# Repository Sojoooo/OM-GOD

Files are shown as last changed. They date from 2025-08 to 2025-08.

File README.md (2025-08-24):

<h1 align="center">
  <br>
  OM-GOD
  <br>
</h1>

<h4 align="center">
Ominichord [Gate of Divinity]. Mash-up of all the previous omnichords and more.
</h4>

<div align="center">





</div>

<p align="center">
  <a href="#key-features">Key Features</a> •
  <a href="#design-process">Design Process</a> •
  <a href="#pcb">PCB</a> •
  <a href="#bom">BOM</a> •
  <a href="#journal">Development Journal</a> •
  <a href="#credits">Credits</a> •
  <a href="#license">License</a>
</p>

## Key Features

- **STM32H7 microcontroller** for high-performance processing
- **Texas Instruments DACs and amplifiers** for professional audio quality
- **MIDI connectivity** for external device integration
- **USB-C programming and power delivery**
- **Battery-powered portable design**
- **Cherry MX mechanical switches** for tactile feedback
- **48-button chord matrix** (4 rows × 12 buttons)
- **Rotary encoders** for parameter control
- **LED display** for status and settings

## Design Process

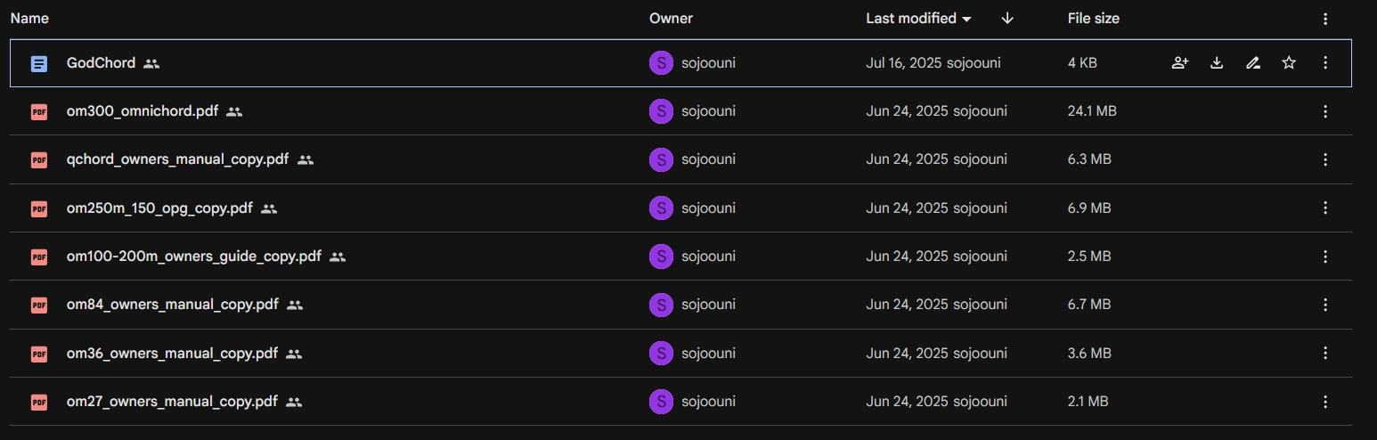
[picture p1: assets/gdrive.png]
Google Drive Reference


The OM-GOD project began with extensive research into existing omnichord designs and their features. After compiling schematics and manuals, I created a comprehensive feature list to guide the development process.

## PCB

Designed in KiCad with a focus on audio quality and modern features. Notable components:

- **STM32H7** microcontroller with 144 GPIO pins
- **PCM5122PW DAC** for high-quality audio conversion
- **TPA3116D2DAD Class D amplifier** for powerful audio output
- **BQ24610** battery charging circuit for portable operation
- **Multiple voltage regulators** (12V, 15V, 5V, 3.3V)
- **USB-C power delivery** with negotiator circuit
- **NFC antenna** for contactless communication

### Schematic Development

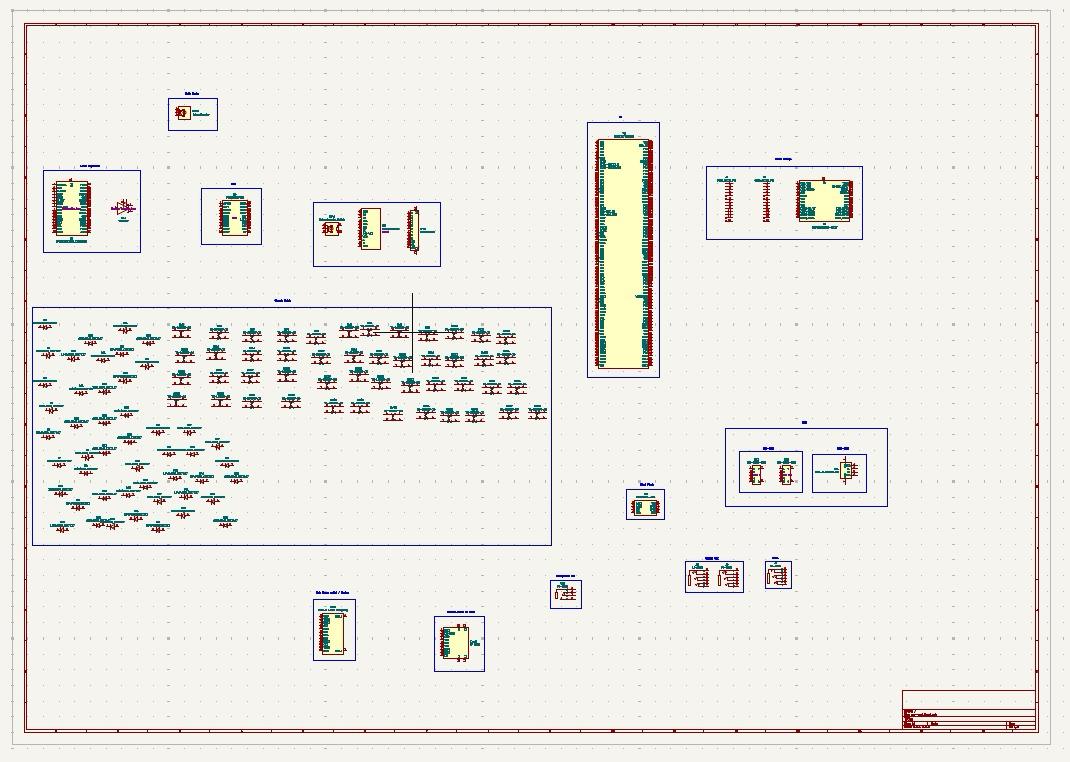
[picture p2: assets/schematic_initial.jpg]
Initial Schematic

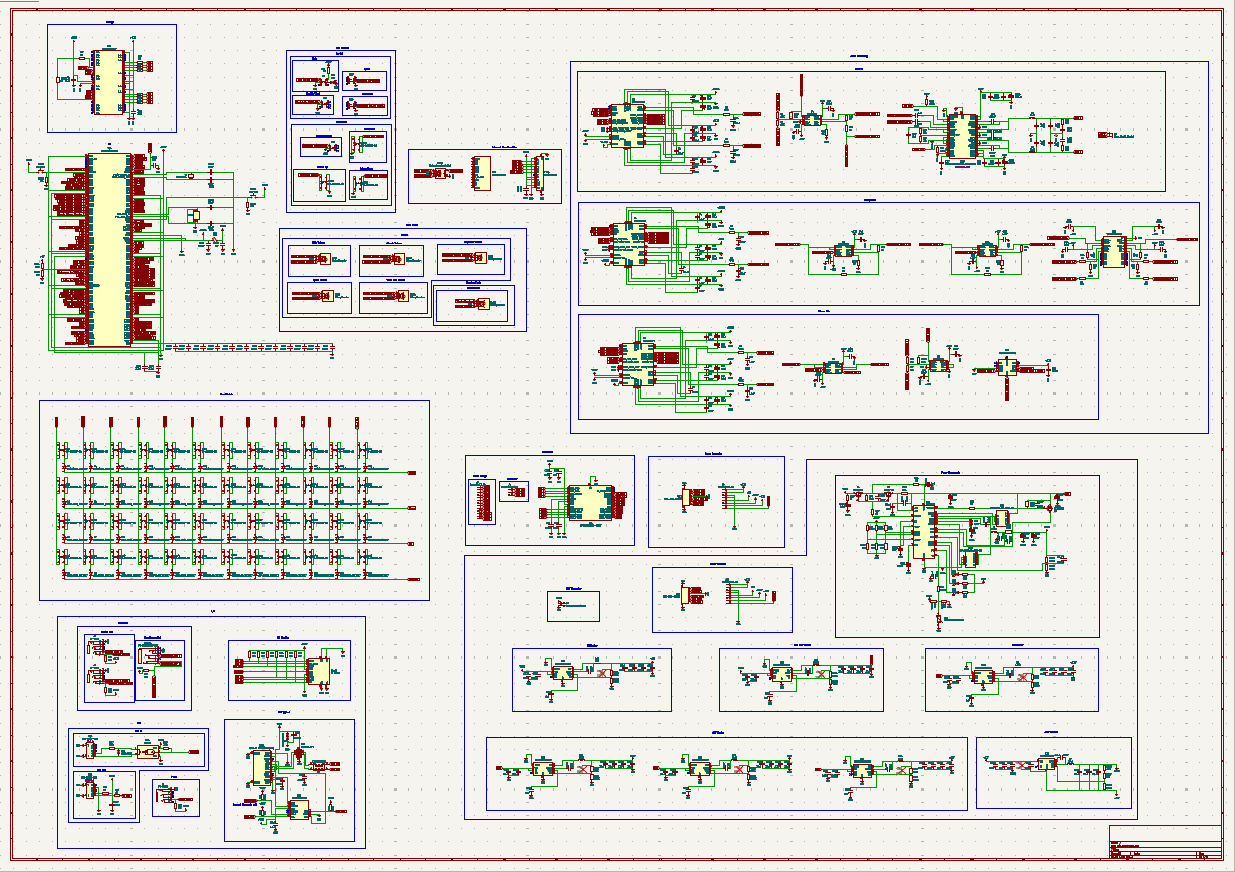
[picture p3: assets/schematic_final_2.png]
Final Schematic


The schematic evolved through multiple iterations, starting with basic component selection and progressing to a complete audio system with power management, I/O interfaces, and user controls.

### Component Integration

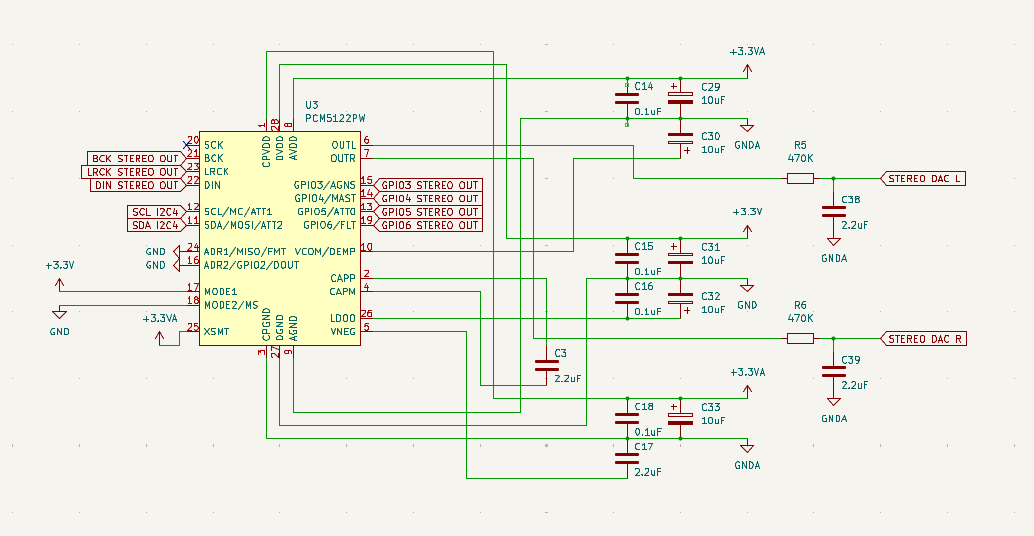
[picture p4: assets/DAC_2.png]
DAC Wiring

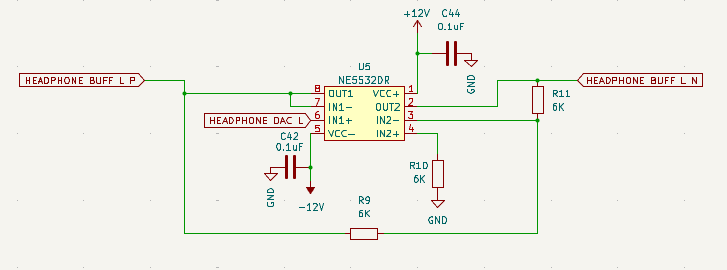
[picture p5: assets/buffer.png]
Buffer Wiring


Key integration challenges included:

- Audio signal buffering for noise reduction
- Power distribution for multiple voltage rails
- Component placement optimization
- Signal integrity considerations

### PCB

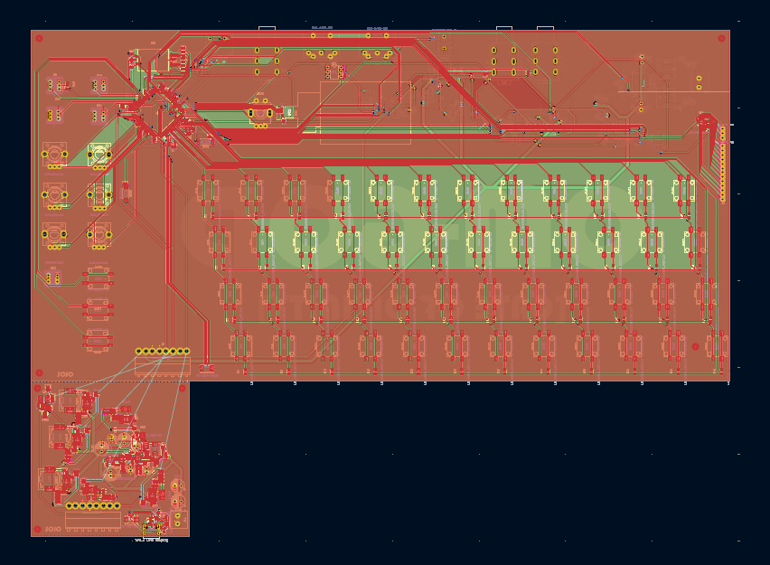
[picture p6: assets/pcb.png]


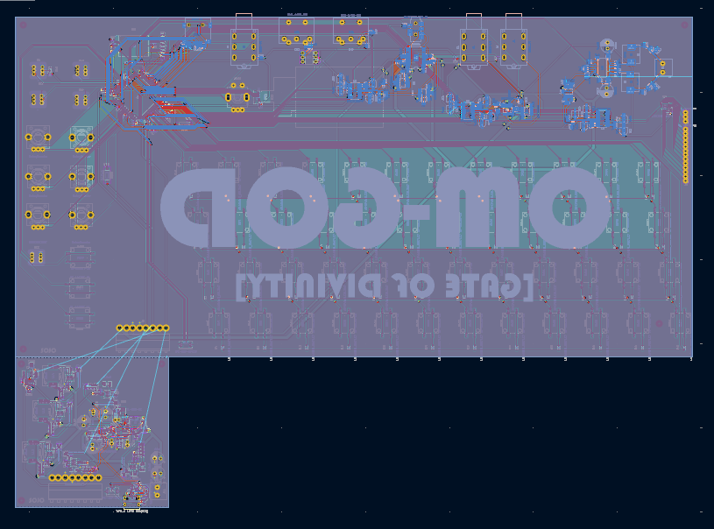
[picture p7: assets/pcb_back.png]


The PCB layout was made to ensure a proper audio quality. All analog traces  and chips are on the bottom layer, while digital traces are on the top. Also, the gnd plane in the inner bottom layer acts as a faraday's cage, not letting them interfier with each other.

### Final Design

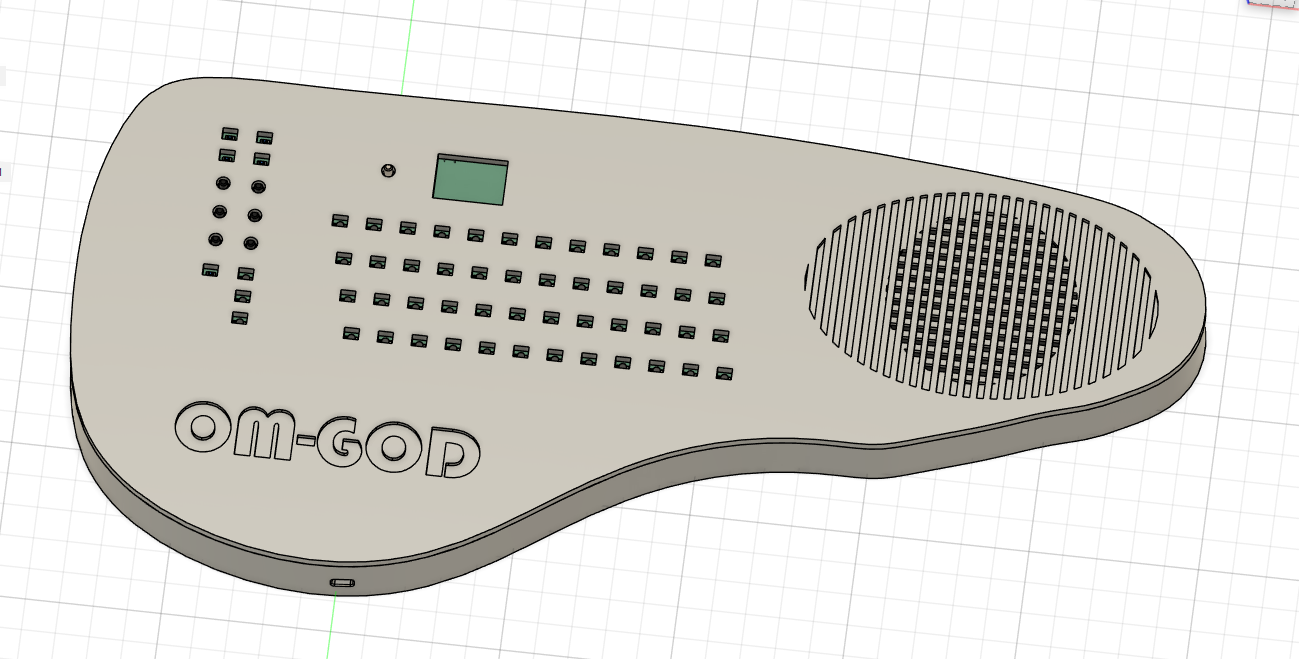
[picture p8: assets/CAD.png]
CAD Design


The final design incorporates all planned features while maintaining a compact, portable form factor suitable for live performance.

## BOM

| Component  | Source | Cost (USD)  |
| ---  | --- | --- |
| PCB | JLCPCB | $348.25 |
| SPEAKER | MERCADO LIBRE | $7.00 |
| FLEX CABLE | MERCADO LIBRE | $4.42 |
| JST CABLE  | MERCADO LIBRE | $5.00 |
| **Total**  | | **364.67** |

_Note: Speakers, keycaps, and case are already owned components from previous projects._

## Credits

This project uses:

- [KiCad](https://www.kicad.org/) - PCB design
- [STM32](https://www.st.com/en/microcontrollers-microprocessors/stm32h7-series.html) - Microcontroller
- [Texas Instruments](https://www.ti.com/) - Audio and power components
- [Fusion 360](https://www.autodesk.com/products/fusion-360/) - 3D modeling

## License

MIT

---

> GitHub [@Sojooo](https://github.com/Sojooo)

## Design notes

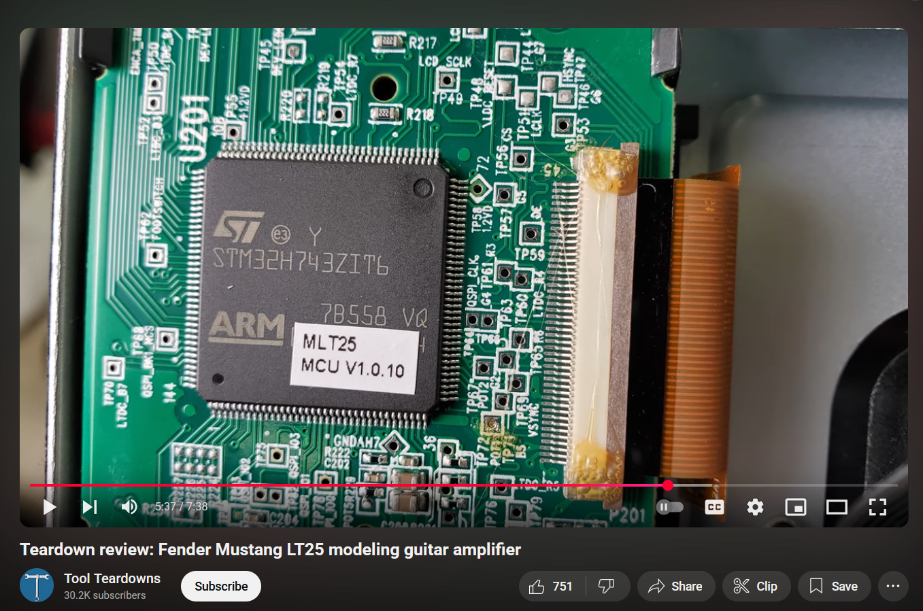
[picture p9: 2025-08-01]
assets/fender_mustang_stm.png

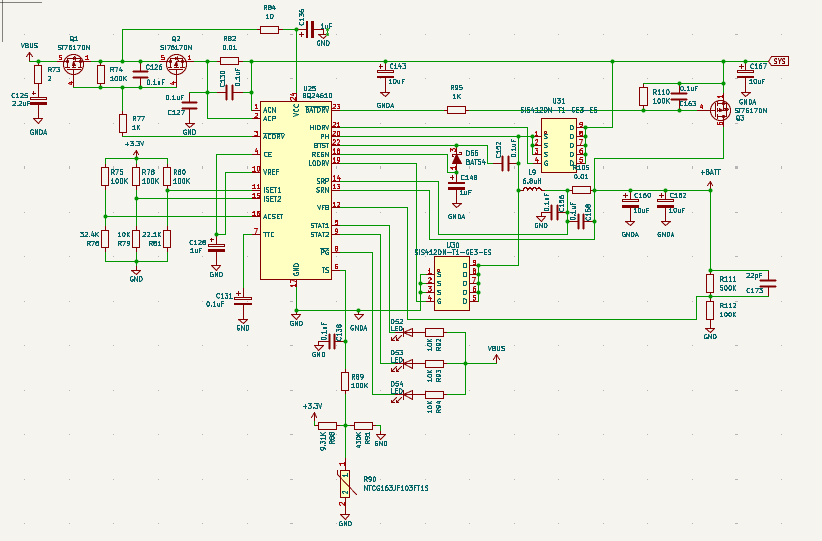
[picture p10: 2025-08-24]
assets/power_manager.png

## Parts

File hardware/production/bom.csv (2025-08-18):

Designator | Footprint | Quantity | Value | LCSC Part #
AUDIO1 | AUDIO-SMD_PJ-393 | 1 | PJ-393_C2837065 | C2837065
C1, C12, C17, C188, C196, C2, C3, C34, C35, C36, C37, C38, C39, C7, C81 | 0402 | 15 | 2.2uF
C10, C11, C13, C134, C14, C15, C150, C16, C18, C198, C4, C40, C42, C43, C44, C45, C5, C51, C53, C54, C55, C6, C60, C61, C62, C75, C76, C79, C8, C80, C83, C84, C9 | 0402 | 33 | 0.1uF
C100, C140, C144, C146, C151, C155, C159, C161, C164, C166, C172, C174, C175, C178, C98 | 0402 | 15 | 100nF
C102, C104 | CP_Radial_D8.0mm_P3.50mm | 2 | 220uF
C109, C110, C115, C116 | 0603 | 4 | 1uF
C122, C123 | 0603 | 2 | 10nF
C165, C191, C67, C72, C73, C82 | 0402 | 6 | 1uF
C168, C169 | 0402 | 2 | 5.1pF
C170, C171 | 0402 | 2 | 5.6pF
C19, C20, C21, C22, C23, C24, C25, C26, C27, C28, C29, C30, C31, C32, C33 | CAP-SMD_BD4.0-L4.3-W4.3-FD | 15 | 10uF
C41 | 0603 | 1 | 0.1uF
C58 | 0402 | 1 | 100uF
C77, C86, C88 | 0402 | 3 | 1nF
C93, C94, C95, C96 | 0402 | 4 | 220nF
CARD1 | TF-SMD_TF-PUSH | 1 | TF PUSH | C393941
CN1, CN2 | CONN-TH_DIN-504B-M10 | 2 | DIN-504B-M10 | C2939346
D1, D10, D11, D12, D13, D14, D15, D16, D17, D18, D19, D2, D20, D21, D22, D23, D24, D25, D26, D27, D28, D29, D3, D30, D31, D32, D33, D34, D35, D36, D37, D38, D39, D4, D40, D41, D42, D43, D44, D45, D46, D47, D48, D5, D6, D7, D8, D9 | SOD-323_L1.8-W1.3-LS2.5-RD | 48 | 1N4148WS_C917117 | C917117
D49 | LED0603-RD | 1 | LED | C5656657
D50 | D_SOD-523 | 1 | 1N4148WT
FB1 | 0603 | 1 | 100
FPC1 | FPC-SMD_5034801200 | 1 | 5034801200 | C587969
J1, J2, J5 | AUDIO-TH_PJ-625G | 3 | PJ-625G | C309300
J3 | PinHeader_1x13_P2.54mm_Vertical | 1 | Conn_01x13_Pin
J4 | PinHeader_1x03_P2.54mm_Vertical | 1 | Conn_01x03_Pin
J6 | CONN-TH_B8PS-VH-LF-SN | 1 | Conn_01x08_Pin | C157970
J9 | CONN-TH_2P-P5.00_WJ500V-5.08-2P | 1 | Conn_01x02_Socket | C8465
L5, L6 | IND-SMD_L11.0-W10.5_SL1050-330M | 2 | 10uH
OC1 | DIP-6_W7.62mm_LongPads | 1 | H11L1
R1, R2, R3, R4, R5, R6 | 0402 | 6 | 470K
R10, R11, R19, R20, R24, R55, R56, R57, R9 | 0402 | 9 | 6K
R100, R101, R102, R103, R96, R97, R98, R99 | 0402 | 8 | 22
R109, R115, R116, R133, R135, R16, R17, R22, R23, R29, R52, R58, R59, R60, R61, R62, R63, R7, R8 | 0402 | 19 | 10k
R117, R31, R32, R36, R37, R38, R39, R54, R83, R87 | 0402 | 10 | 1K
R134 | 0402 | 1 | 4.7k
R18 | 0402 | 1 | 5K
R26 | 0402 | 1 | 33
R27 | 0402 | 1 | 220
R28 | 0402 | 1 | 10
R35 | 0402 | 1 | 470
R42 | 0402 | 1 | 47k
R43 | 0402 | 1 | 75k
R46, R49 | 0402 | 2 | 100k
R68, R69 | 0402 | 2 | 3.3
SW1, SW11, SW12, SW13, SW14, SW15, SW16, SW17, SW18, SW2, SW21, SW22, SW23, SW24, SW25, SW26, SW27, SW28, SW29, SW3, SW30, SW31, SW32, SW35, SW36, SW37, SW38, SW39, SW4, SW40, SW41, SW42, SW43, SW44, SW45, SW46, SW47, SW48, SW49, SW50, SW51, SW52, SW53, SW54, SW55, SW56, SW57, SW6, SW7, SW8, SW9 | SW-SMD_4P-L12.0-W12.0-P5.00-LS15.4 | 51 | TS-1003ST-26 | C455234
SW10, SW19, SW20, SW33, SW34, SW5 | SW-TH_EC12EXXXX | 6 | RotaryEncoder | C470684
SW58, SW60 | SW_SPST_CK_RS282G05A3 | 2 | SW_Push
SW61 | SW-TH_EC11E15244G1 | 1 | RotaryEncoder_Switch
U1, U2, U3 | TSSOP-28_4.4x9.7mm_P0.65mm | 3 | PCM5122PW
U10, U12, U13, U14, U9 | SW-TH_6P-L7.0-W7.0-P2.00_7-7-ZS | 5 | ~ | C5379891
U11, U20, U4, U5, U6, U8 | SOIC-8_L4.9-W3.9-P1.27-LS6.0-BL | 6 | NE5532DR | C7426
U15 | UQFN-10_L2.0-W1.5-P0.50-BL-EP | 1 | TS5A23159RSER | C138710
U17 | HSOP-20_L12.8-W7.5-P1.27-LS10.3-BL-EP3.3 | 1 | TPA6120A2DWP | C2871054
U19 | HTSSOP-32_L11.0-W6.1-P0.65-LS8.1-BL | 1 | TPA3116D2DAD_C2865736 | C2865736
U21 | QFN-24_L4.0-W4.0-P0.50-BL-EP2.6 | 1 | CY8CMBR3116-LQXIT | C914913
U22 | FPC-SMD_6P-P0.50_XUNPU_FPC-05F-6PH20 | 1 | FPC-05F-6PH20 | C2856796
U27 | TSOP-48_L12.0-W18.4-P0.50-LS20.0-TL | 1 | W29N02KVSIAF | C2940193
U32 | CRYSTAL-SMD_4P-L3.2-W2.5-BL_SIT8008BI | 1 | ~ | C7294602
U33 | OLED-SMD_HS20HS072RX | 1 | HS20HS072RX | C5329582
VQ1 | LQFP-144_L20.0-W20.0-P0.50-LS22.0-BL | 1 | STM32H723ZGT6 | C730146
Y1 | FC-135R_L3.2-W1.5 | 1 | 32.768KHz

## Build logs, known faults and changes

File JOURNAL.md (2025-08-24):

---
title: "OM-GOD"
author: "Juan Pablo Sojo (Sojooo)"
description: "Ominichord [Gate of Divinity]. Mash-up of all the previous omnichords and more."
created_at: "2025-07-14"
time_spent: ~110 Hours
---

# July 14: Planning

I have always been in love with music, so much so that I recently found a cool instrument that was made a while back called an omnichord. For those who don't know what it is, it's a musical instrument that allows you to play synth chords while overlaying notes of the chord among other functionality. It has a unique sound and there aren't really any other "instruments" that come close to it. I wanted to have one, but there was a problem: they don't make them anymore and the current ones cost upwards of hundreds of dollars (which I don't have), so I decided to make my own.

I wanted my omnichord to be a mashup of all the previous omnichords, including all of their functionality and also bringing a few modern bits like a display and maybe bluetooth.

Then I created a Google Drive folder and started compiling the schematics for later reference.

Google Drive Folder

**Hours: 6**

# July 15: Reading Manuals

After compiling the manuals, I went through the laborious task of reading all of them and compiling a list of features that each one had and their pros and cons. I compiled this list into a Google Docs document.

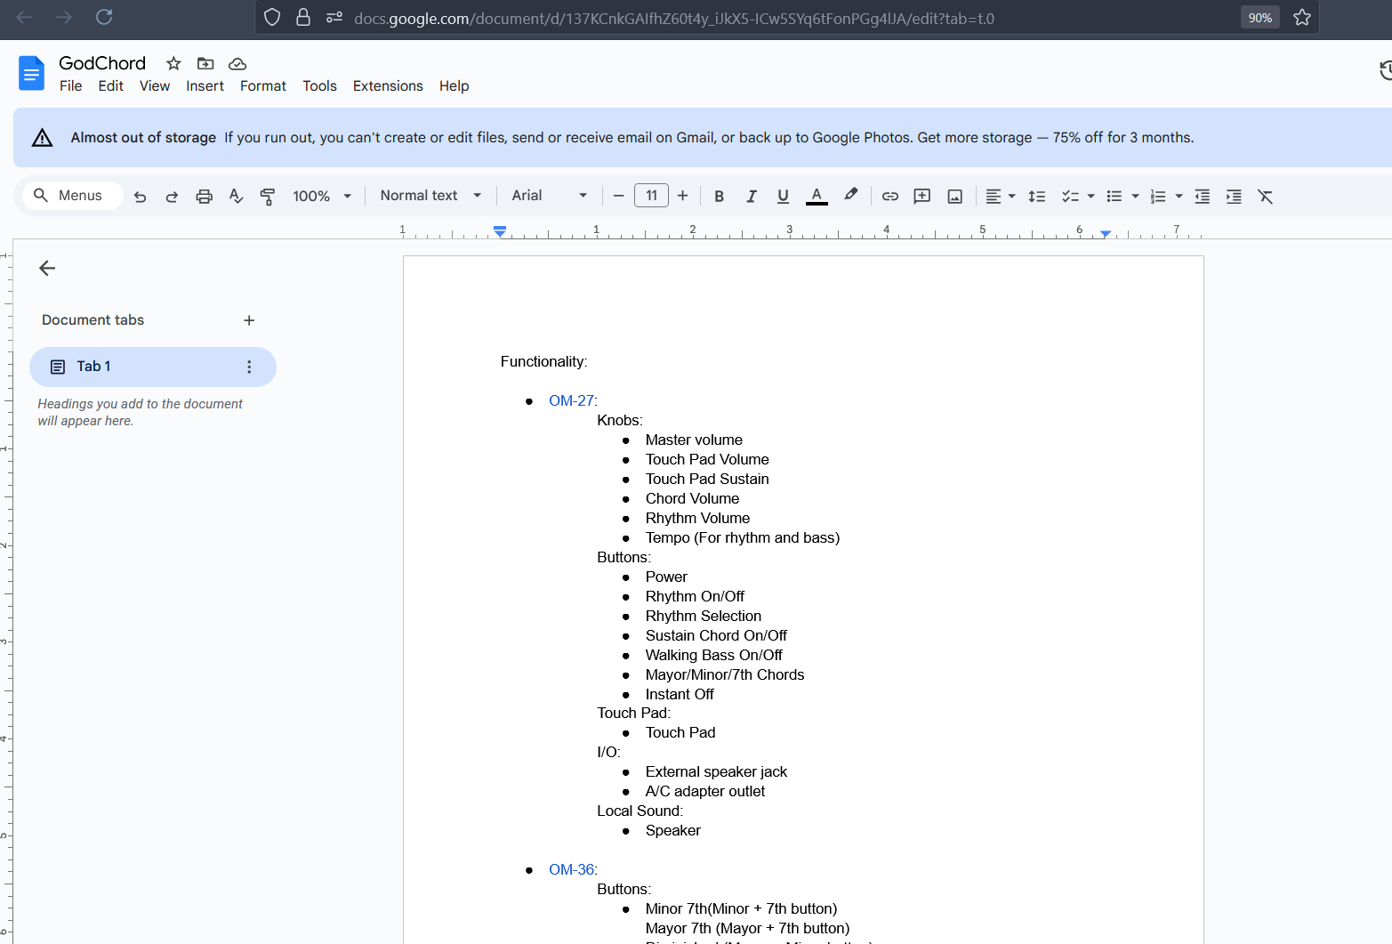
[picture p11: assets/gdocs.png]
Google Docs Reference


Now that I had the comprehensive list of features that I wanted to add, I started work on finding the right components.

**Hours: 7**

# July 18: Learning and Component Selection

For reference, this is my first big project, so I had no idea what I was doing. I started watching tutorials. After looking through the schematic of the original omnichord, I found that they used custom ICs and clocks to generate the waves to create the audio. I needed a way to replicate this but also make it modern, so I looked to my guitar amp, which is a Fender Mustang. The Fender Mustang has a screen and a cool pushbutton rotary encoder, so I wanted to incorporate that into the omnichord as well.

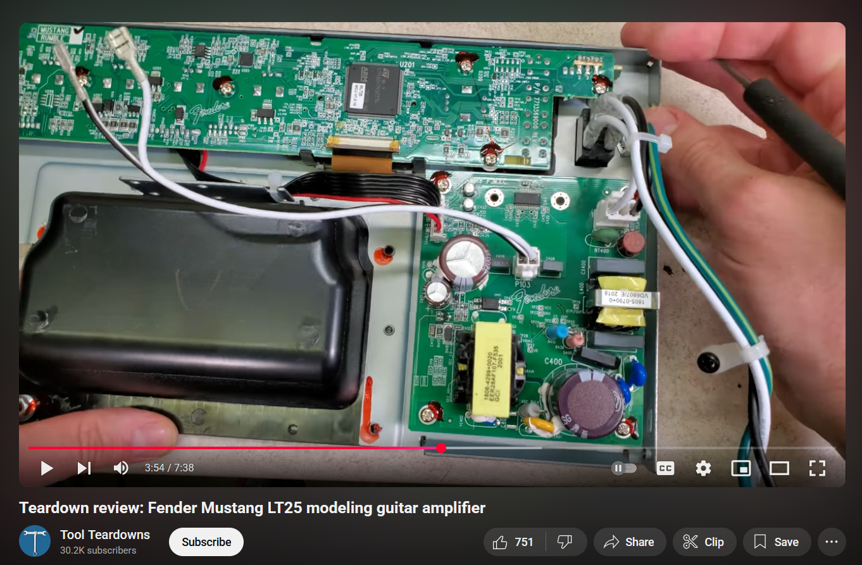
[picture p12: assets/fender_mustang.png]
Fender Mustang Reference


After watching several teardown videos, I saw that it uses an STM32H7 chip, and I've heard that those are pretty fast and have a lot of GPIO, so that's what I wanted to use.

**Hours: 7**

# July 19: More Component Selection

I wanted to have 3 speakers: a subwoofer, woofer, and tweeter. I also wanted a stereo out and a headphones out. All this could have been too much current for just one DAC, so I had to add sufficient DACs. This led me to spend a long time searching through the datasheets and learning about the different classes of DACs and amps. I finally ended up with a DAC named PCM5122PW and a class D amp called TPA3116D2DAD from Texas Instruments (I love Texas Instruments). These I have seen to be widely used and they have good support, so I added them to the schematic.

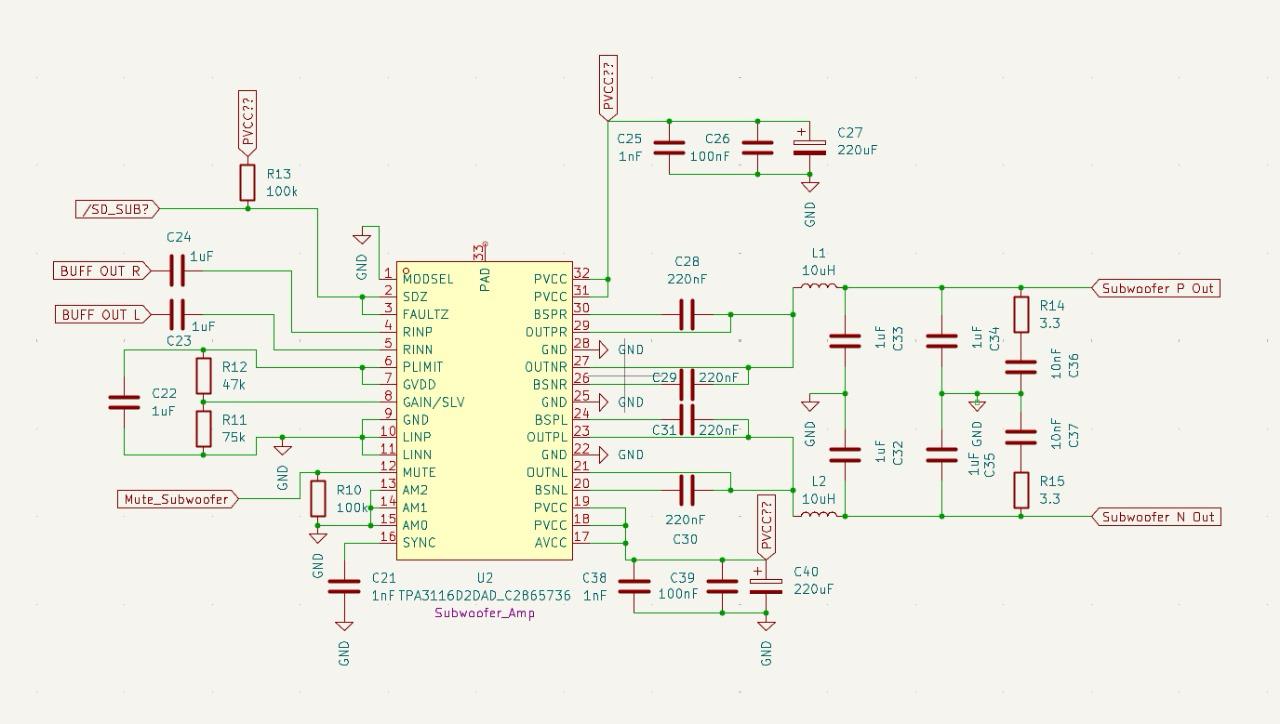
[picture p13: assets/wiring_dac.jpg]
DAC Wiring


**Hours: 7**

# July 20: I/O

After adding the DACs, I started work on the different audio connectors that I wanted to add. Besides the ones mentioned before, i also wanted to add a midi in/midi out. I then researched and found out that MIDI is basically fancy UART, so I found a connector on LCSC and added it to the schematic (I'm reading the datasheets later). Then I found some jacks and added them as well. I wanted this feature so that when you plug only one line in, it's mono, and if you plug both then it's stereo, so I added a multiplexer TS5A23159RSER.

After re-reading over my work from the days before, I started having doubts about the audio quality, so I asked a teacher that studied electronic engineering and he said that I might need a buffer so that the sound signal has strength and isn't noisy or weak. I spent the rest of the day researching buffers and adding one into the schematic, so I chose the NE5532DR.

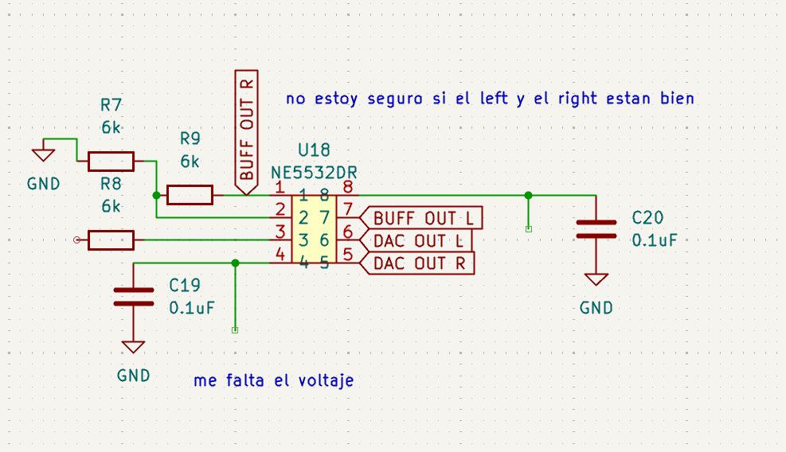
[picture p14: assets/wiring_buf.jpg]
Buffer Wiring


**Hours: 7**

# July 21: Biggest issue

After adding the DAC, and finish all the buffering and filtering of the different audio systems incorporated, i wanted to finally solve the problem: how would the user control the volume? I first thought about pots, which are usually whats used in DIY proyects. The problem with pots was that if i used actual pots with knobs, then the user would need to separatly control the headphones volume, the stereo out volume, and the speakers volume, which i didn't want. Also, i think finding log taper pots in lcsc is quite the challenge, which is crucial for a good volume gradient. Plan B was using digipots, but there arent any good audio quality digipots in the market for some reason. I then asked myself: how do car audio systems work? how is volume handled profesionally? I finally found that you could control it from the DAC, as long as it had a I2C to get all this info from the MCU. Because of this, I ended up updating all three DACs from PCM5102A to PCM5122. This took me a lot of time to solve.

DAC Wiring

# July 22: Buttons and Switches

I wanted to have enough buttons and stuff to make a bunch of chord combinations, so I made 4 rows of 12 buttons, one for each note, and each row corresponds to major, minor, 7th, and extensions.

I used Cherry MX keys as I had experience with them from making a hackpad.

**Hours: 5**

# July 23-25: Power

I wanted this omnichord to be mobile, so I had to add batteries, and if I added batteries then I needed a battery charging circuit (Texas Instruments to the rescue). I added a nice battery charging circuit (BQ24610). It was then that I realized that I needed 12V to power all of the speakers and DACs, so I had to create various buck converters and boost converters to convert from 12V to 15V, 3.3V, and 5V. I also was worried about the amperage, so I added various components in parallel to feed into the 5A that the DACs and amps needed. This took me a while to find the components because I first thought I needed 3.3V but then had the realization that audio needs a lot of power.

**Hours: 21** (7 hours each day)

# July 26: Power Continued and Other I/O

I needed a way to program the STM, so I added USB-C, and I wanted to be able to power the batteries for the amps, so I had to add a USB-C power negotiator circuit.

After that, I wanted to add more rotaries and an LED screen with a header, so I was working on that.

**Hours: 7**

# July 26-30: Datasheet Analysis and Finish Schematic

After placing all of the components, I had to connect all of the components, so I read through all the datasheets and pulled a few all-nighters to do that. I ended up using all 144 pins on the STM32H7 and struggled a bit with the power placement.

Initial Schematic

**Hours: 28** (7 hours each day for 4 days)

# July 31: Final Stretch

I finally finished the schematic and in a frenzy started wiring the PCB. I used FreeRouter and wired the components up, although I plan on making it better later, but I had to submit because of the deadline. I then went to Fusion and designed the case and finished up the project.

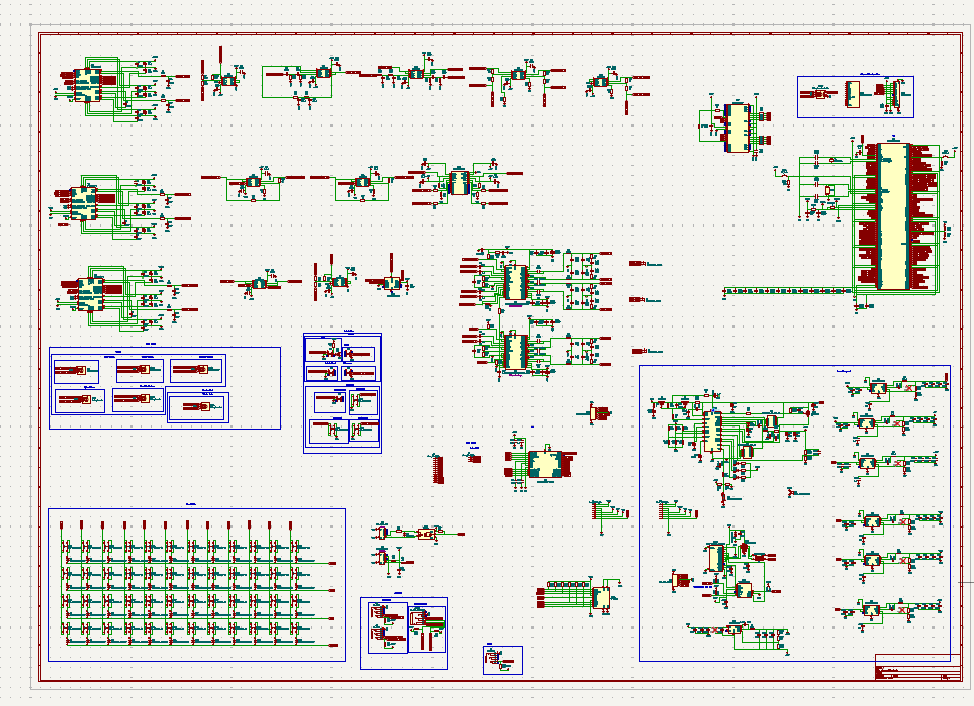
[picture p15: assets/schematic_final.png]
Final Schematic


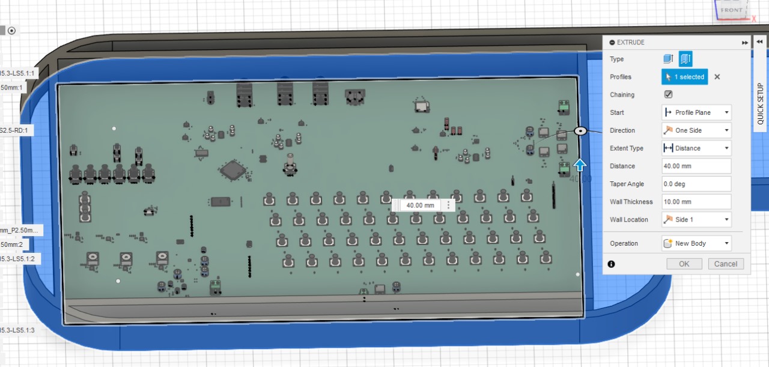
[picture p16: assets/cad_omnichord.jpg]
CAD Design


**Hours: 5**

---

**_Total Hours: 110_**

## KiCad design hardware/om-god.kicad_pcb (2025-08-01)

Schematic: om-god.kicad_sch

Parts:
AUDIO1: PJ-393_C2837065; AUDIO-SMD_PJ-393; LCSC Part C2837065
C1, C2, C3, C7, C12, C17, C34, C35, C36, C37, C38, C39, C81, C188, C196: 2.2uF; C_0402_1005Metric
C4, C5, C6, C8, C9, C10, C11, C13, C14, C15, C16, C18, C40, C42, C43, C44, C45, C50, C51, C52, C53, C54, C55, C59, C60, C61, C62, C63, C75, C76, C79, C80, C83, C84, C124, C126, C127, C130, C133, C134, C138, C139, C141, C147, C150, C152, C153, C156, C158, C163, C198, C199, C200, C201, C202, C203, C206: 0.1uF; C_0402_1005Metric
C19, C20, C21, C22, C23, C24, C25, C26, C27, C28, C29, C30, C31, C32, C33: 10uF; CAP-SMD_BD4.0-L4.3-W4.3-FD
C41, C117: 0.1uF; C_0603_1608Metric
C46, C47: 82nF; C_Rect_L4.0mm_W2.5mm_P2.50mm
C48, C49, C64, C65: 5.6nF; C_Rect_L4.0mm_W2.5mm_P2.50mm
C56, C57: 82nF; C_0603_1608Metric
C58: 100uF; C_0402_1005Metric
C66, C67, C68, C69, C70, C71, C72, C73, C82, C165, C189, C190, C191, C193, C194, C195, C197: 1uF; C_0402_1005Metric
C74: 10nF; C_0402_1005Metric
C77, C85, C86, C87, C88: 1nF; C_0402_1005Metric
C78, C97, C98, C99, C100, C140, C144, C145, C146, C151, C155, C159, C161, C164, C166, C172, C174, C175, C178: 100nF; C_0402_1005Metric
C89, C90, C91, C92, C93, C94, C95, C96, C185, C186, C187: 220nF; C_0402_1005Metric
C101, C102, C103, C104: 220uF; CP_Radial_D8.0mm_P3.50mm
C105, C106, C107, C108: 680nF; C_0603_1608Metric
C109, C110, C111, C112, C113, C114, C115, C116: 1uF; C_0603_1608Metric
C118, C119, C120, C121, C122, C123: 10nF; C_0603_1608Metric
C125: 2.2uF; CP_Radial_D8.0mm_P2.50mm
C128, C136, C148: 1uF; CP_Radial_D5.0mm_P2.00mm
C129, C132: 10uF; C_0402_1005Metric
C131: 0.1uF; CP_Radial_D5.0mm_P2.00mm
C137: 10uF; C_0402_1005Metric; not fitted
C142, C149: 220pF; C_0402_1005Metric
C143, C160, C162, C167: 10uF; CP_Radial_D8.0mm_P3.50mm
C154, C157: 22uF; C_0402_1005Metric
C168, C169: 5.1pF; C_0402_1005Metric
C170, C171: 5.6pF; C_0402_1005Metric
C173: 22pF; C_0402_1005Metric
C176, C177, C179, C180, C181, C184: 10uF; C_0603_1608Metric
C182, C183, C192: 220nF; C_0603_1608Metric
C204, C205, C210: 47pF; C_0402_1005Metric; not fitted
C207, C208, C209: 47pF; C_0603_1608Metric; not fitted
C211, C212, C213, C214, C215, C216, C217, C218, C219, C220, C221, C222, C223, C224, C225, C226, C227, C228, C229, C230, C231, C232, C233, C234: 22uF; C_0603_1608Metric
CN1, CN2: DIN-504B-M10; CONN-TH_DIN-504B-M10; LCSC Part C2939346
Card1: TF PUSH; TF-SMD_TF-PUSH; LCSC Part C393941
D1, D2, D3, D4, D5, D6, D7, D8, D9, D10, D11, D12, D13, D14, D15, D16, D17, D18, D19, D20, D21, D22, D23, D24, D25, D26, D27, D28, D29, D30, D31, D32, D33, D34, D35, D36, D37, D38, D39, D40, D41, D42, D43, D44, D45, D46, D47, D48: 1N4148WS_C917117; SOD-323_L1.8-W1.3-LS2.5-RD; LCSC Part C917117
D49: LED; LED0603-RD; LCSC C5656657
D50: 1N4148WT; D_SOD-523
D51: PESD15VL1BA; D_SOD-323_TVS
D52, D53, D54: LED; LED_0603_1608Metric
D55: BAT54; SOT-23
FPC1: 5034801200; FPC-SMD_5034801200; LCSC Part C587969
J1, J2, J5: PJ-625G; AUDIO-TH_PJ-625G; LCSC Part C309300
J3: Conn_01x13_Pin; PinHeader_1x13_P2.54mm_Vertical
J4: Conn_01x03_Pin; PinHeader_1x03_P2.54mm_Vertical
J6, J10: Conn_01x08_Pin; CONN-TH_B8PS-VH-LF-SN; LCSC C157970
J7, J8, J9, J11: Conn_01x02_Socket; CONN-TH_2P-P5.00_WJ500V-5.08-2P; LCSC C8465
L1, L2, L3, L4, L5, L6: 10uH; IND-SMD_L11.0-W10.5_SL1050-330M
L7: 27uH; IND-SMD_L4.8-W3.4
L8: EXC14CE900U; FILTER-SMD_4P-L0.9-W0.7-P0.50-BL; LCSC Part C178761
L9: 6.8uH; L_6.3x6.3_H3
L10: 8uH; L1206
L11, L15: 6.8uH; IND-SMD_L3.2-W2.5_L3225
L12, L13, L14: 15uH; IND-SMD_L12.3-W12.3
OC1: H11L1; DIP-6_W7.62mm_LongPads
Q1, Q2, Q3: Si7617DN; Vishay_PowerPAK_1212-8_Single
R1, R2, R3, R4, R5, R6: 470K; R_0402_1005Metric
R7, R8, R12, R13, R14, R15, R16, R17, R21, R22, R23, R25, R29, R30, R33, R34, R52, R58, R59, R60, R61, R62, R63, R79, R92, R93, R94, R115, R116: 10K; R_0402_1005Metric
R9, R10, R11, R19, R20, R24, R47, R48, R53, R55, R56, R57, R70, R71, R72: 6K; R_0402_1005Metric
R18: 5K; R_0402_1005Metric
R26: 33; R_0402_1005Metric
R27: 220; R_0402_1005Metric
R28, R84: 10; R_0402_1005Metric
R31, R32, R36, R37, R38, R39, R54, R77, R95, R117: 1K; R_0402_1005Metric
R35: 470; R_0402_1005Metric
R40, R42: 47k; R_0402_1005Metric
R41, R43: 75k; R_0402_1005Metric
R44, R45, R46, R49, R50: 100k; R_0402_1005Metric
R51, R109, R133, R135: 10k; R_0402_1005Metric
R64, R65, R66, R67, R68, R69: 3.3; R_0402_1005Metric
R73: 2; R_0402_1005Metric
R74, R75, R78, R80, R89, R110, R112, R121, R123, R125, R127, R129, R131: 100K; R_0402_1005Metric
R76: 32.4K; R_0402_1005Metric
R81: 22.1K; R_0402_1005Metric
R82, R105: 0.01; R_0402_1005Metric
R83, R87: 1k; R_0402_1005Metric
R85: 200K; R_0402_1005Metric
R86, R104: 1.5K; R_0402_1005Metric
R88: 9.31K; R_0402_1005Metric
R90: NTCG163JF103FT1S; R0603; LCSC Part C406719
R91: 430K; R_0402_1005Metric
R96, R97, R98, R99, R100, R101, R102, R103: 22; R_0402_1005Metric
R106: 49.9; R_0402_1005Metric
R107: 50k; R_0402_1005Metric
R108: 2.61k; R_0402_1005Metric
R111: 500K; R_0402_1005Metric
R113, R114: 0; R_0402_1005Metric
R122: 24.9K; R_0402_1005Metric
R124, R132: 43.2K; R_0402_1005Metric
R126, R128, R130: 9.09K; R_0402_1005Metric
R134: 4.7k; R_0402_1005Metric
SW1, SW2, SW3, SW4, SW6, SW7, SW8, SW9, SW11, SW12, SW13, SW14, SW15, SW16, SW17, SW18, SW21, SW22, SW23, SW24, SW25, SW26, SW27, SW28, SW29, SW30, SW31, SW32, SW35, SW36, SW37, SW38, SW39, SW40, SW41, SW42, SW43, SW44, SW45, SW46, SW47, SW48, SW49, SW50, SW51, SW52, SW53, SW54, SW55, SW56, SW57: TS-1003ST-26; SW-SMD_4P-L12.0-W12.0-P5.00-LS15.4; LCSC Part C455234
SW5, SW10, SW19, SW20, SW33, SW34: RotaryEncoder; SW-TH_EC12EXXXX; LCSC C470684
SW58, SW60: SW_Push; SW_SPST_CK_RS282G05A3
SW59: RotaryEncoder_Switch; SW-TH_EC11E1820402; LCSC C361165
U1, U2, U3: PCM5122PW; TSSOP-28_4.4x9.7mm_P0.65mm
U4, U5, U6, U7, U8, U11, U16, U20, U23: NE5532DR; SOIC-8_L4.9-W3.9-P1.27-LS6.0-BL; LCSC Part C7426
U9, U10, U12, U13, U14: SW-TH_6P-L7.0-W7.0-P2.00_7-7-ZS; LCSC C5379891
U15: TS5A23159RSER; UQFN-10_L2.0-W1.5-P0.50-BL-EP; LCSC Part C138710
U17: TPA6120A2DWP; HSOP-20_L12.8-W7.5-P1.27-LS10.3-BL-EP3.3; LCSC Part C2871054
U18, U19: TPA3116D2DAD_C2865736; HTSSOP-32_L11.0-W6.1-P0.65-LS8.1-BL; LCSC Part C2865736
U21: CY8CMBR3116-LQXIT; QFN-24_L4.0-W4.0-P0.50-BL-EP2.6; LCSC Part C914913
U22, U24: FPC-05F-6PH20; FPC-SMD_6P-P0.50_XUNPU_FPC-05F-6PH20; LCSC C2856796
U25: BQ24610; VQFN-24-1EP_4x4mm_P0.5mm_EP2.45x2.45mm
U26: TPS54202DDC; SOT-23-6
U27: W29N02KVSIAF; TSOP-48_L12.0-W18.4-P0.50-LS20.0-TL; LCSC C2940193
U28: USBLC6-2P6; SOT-666
U29: TUSB422IYFPR; DSBGA-9_L1.4-W1.3-R3-C3-P0.40-BL; LCSC Part C702378
U30, U31: SIS412DN-T1-GE3-ES; PDFN-8_L3.1-W3.1-P0.65-LS3.4-BL; LCSC Part C21713860
U32: CRYSTAL-SMD_4P-L3.2-W2.5-BL_SIT8008BI; LCSC C7294602
U33: HS20HS072RX; OLED-SMD_HS20HS072RX; LCSC Part C5329582
U34, U35, U36, U37, U38, U39: LMR33630ADDAR; ESOP-8_L4.9-W3.9-P1.27-LS6.0-TL-EP; LCSC Part C841384
USB1: TYPE-C 16PIN 2MD(073); USB-C-SMD_TYPE-C-6PIN-2MD-073; LCSC Part C2765186
VQ1: STM32H723ZGT6; LQFP-144_L20.0-W20.0-P0.50-LS22.0-BL; LCSC Part C730146
Y1: 32.768KHz; FC-135R_L3.2-W1.5

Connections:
3.3BATT: C191.2, C210.1, C218.1, C224.1, C230.1, C234.1, J6.8, J10.8, L15.2, R131.2, VQ1.6 (VBAT)
7th: D3.1 (C), D7.1 (C), D11.1 (C), D15.1 (C), D19.1 (C), D23.1 (C), D27.1 (C), D31.1 (C), D35.1 (C), D39.1 (C), D43.1 (C), D47.1 (C), VQ1.37 (PA3)
#CE: U27.9, VQ1.98 (PC8)
#RE: U27.8, VQ1.118 (PD4)
#WE: U27.18, VQ1.119 (PD5)
+3.3V: C5.1, C10.1, C15.1, C21.1, C26.1, C31.1, C58.1, C60.1, C80.1, C82.1, C134.2, C140.1, C141.1, C144.1, C146.1, C150.2, C151.1, C155.1, C159.1, C161.1, C164.1, C165.1, C166.1, C174.1, C175.1, C178.1, C198.2, C205.1, C212.1, C217.1, C223.1, C229.1, Card1.4 (VDD), FPC1.8, FPC1.9, FPC1.11, J6.5, J10.5, L11.2, OC1.6 (VCC), R18.2, R22.1, R23.1, R26.1, R29.2, R33.2, R35.2, R52.1, R58.2, R59.2, R60.2, R61.2, R62.2, R63.2, R75.2, R78.2, R80.2, R83.1, R85.1, R86.2, R87.1, R88.1, R104.1, R113.1, R123.2, SW58.2, SW60.2, U1.17 (MODE1), U1.28 (DVDD), U2.17 (MODE1), U2.28 (DVDD), U3.17 (MODE1), U3.28 (DVDD), U15.8 (VCC), U21.7 (VDD), U27.12, U27.34, U27.37, U27.39, U29.A3 (VDD), VQ1.17 (VDD), VQ1.30 (VDD), VQ1.39 (VDD), VQ1.52 (VDD), VQ1.62 (VDD), VQ1.72 (VDD), VQ1.84 (VDD), VQ1.95 (VDD33USB), VQ1.108 (VDD), VQ1.121 (VDD), VQ1.131 (VDD), VQ1.144 (VDD)
+3.3VA: C4.1, C8.1, C9.1, C13.1, C14.1, C18.1, C19.1, C23.1, C24.1, C28.1, C29.1, C33.1, C172.1, R113.2, R114.1, R114.2, U1.1 (CPVDD), U1.8 (AVDD), U1.25 (XSMT), U2.1 (CPVDD), U2.8 (AVDD), U2.25 (XSMT), U3.1 (CPVDD), U3.8 (AVDD), U3.25 (XSMT), VQ1.32 (VREF+), VQ1.33 (VDDA)
+5V: C204.1, C211.1, C216.1, C222.1, C228.1, J6.6, J10.6, L10.2, R121.2, R134.2
+12V: C41.2, C44.2, C45.2, C52.2, C54.2, C55.2, C61.1, C63.2, C74.1, C76.1, C84.2, C85.2, C86.2, C87.2, C88.2, C97.2, C98.2, C99.2, C100.2, C101.1, C102.1, C103.1, C104.1, C124.2, C129.1, C132.1, C133.1, C137.1, C139.1, C207.1, C208.1, C209.1, C213.1, C214.1, C215.1, C219.1, C220.1, C221.1, C225.1, C226.1, C227.1, C231.1, C232.1, C233.1, J6.1, J6.2, J10.1, J10.2, L12.2, L13.2, L14.2, R45.1, R46.1, R50.2, R125.2, R127.2, R129.2, U4.1 (VCC+), U5.1 (VCC+), U6.1 (VCC+), U7.1 (VCC+), U8.1 (VCC+), U11.1 (VCC+), U16.1 (VCC+), U17.3 (LVCC+), U17.18 (RVCC+), U18.17 (AVCC), U18.18 (PVCC), U18.19 (PVCC), U18.31 (PVCC), U18.32 (PVCC), U19.17 (AVCC), U19.18 (PVCC), U19.19 (PVCC), U19.31 (PVCC), U19.32 (PVCC), U20.1 (VCC+), U23.1 (VCC+), U26.3 (VIN)
+BATT: C158.1, C160.1, C162.1, C173.2, C184.1, C192.1, J11.1, Q3.5 (D), R105.2, R111.1, U25.13 (SRN), U39.2 (VIN), U39.3 (EN)
-12V: C40.2, C42.2, C43.2, C50.2, C51.2, C53.2, C59.2, C62.2, C75.2, C79.2, C117.2, C137.2, C139.2, C153.2, C154.2, C157.2, J6.7, J10.7, R108.1, U4.5 (VCC-), U5.5 (VCC-), U6.5 (VCC-), U7.5 (VCC-), U8.5 (VCC-), U11.5 (VCC-), U16.5 (VCC-), U17.1 (LVCC-), U17.20 (RVCC-), U20.5 (VCC-), U23.5 (VCC-), U26.1 (GND)
ALE: U27.17, VQ1.81 (PD12)
BCK HEADPHONE: U1.21 (BCK), VQ1.69 (PB10)
BCK SPEAKER: U2.21 (BCK), VQ1.41 (PA5)
BCK STEREO OUT: U3.21 (BCK), VQ1.133 (PB3)
CLE: U27.16, VQ1.80 (PD11)
Chord A: SW1.3, SW1.4, SW2.3, SW2.4, SW3.3, SW3.4, SW4.3, SW4.4, VQ1.7 (PC13)
Chord Ab: SW51.3, SW51.4, SW52.3, SW52.4, SW53.3, SW53.4, SW54.3, SW54.4, VQ1.28 (PC2_C)
Chord B: SW11.3, SW11.4, SW12.3, SW12.4, SW13.3, SW13.4, SW14.3, SW14.4, VQ1.13 (PF3)
Chord Bb: SW6.3, SW6.4, SW7.3, SW7.4, SW8.3, SW8.4, SW9.3, SW9.4, VQ1.12 (PF2)
Chord C: SW15.3, SW15.4, SW16.3, SW16.4, SW17.3, SW17.4, SW18.3, SW18.4, VQ1.14 (PF4)
Chord D: SW25.3, SW25.4, SW26.3, SW26.4, SW27.3, SW27.4, SW28.3, SW28.4, VQ1.18 (PF6)
Chord Db: SW21.3, SW21.4, SW22.3, SW22.4, SW23.3, SW23.4, SW24.3, SW24.4, VQ1.15 (PF5)
Chord E: SW35.3, SW35.4, SW36.3, SW36.4, SW37.3, SW37.4, SW38.3, SW38.4, VQ1.20 (PF8)
Chord Eb: SW29.3, SW29.4, SW30.3, SW30.4, SW31.3, SW31.4, SW32.3, SW32.4, VQ1.19 (PF7)
Chord F: SW39.3, SW39.4, SW40.3, SW40.4, SW41.3, SW41.4, SW42.3, SW42.4, VQ1.21 (PF9)
Chord G: SW47.3, SW47.4, SW48.3, SW48.4, SW49.3, SW49.4, SW50.3, SW50.4, VQ1.26 (PC0)
Chord Gb: SW43.3, SW43.4, SW44.3, SW44.4, SW45.3, SW45.4, SW46.3, SW46.4, VQ1.22 (PF10)
Chords Volume Encoder A: SW19.A, VQ1.127 (PG12)
Chords Volume Encoder B: SW19.B, VQ1.126 (PG11)
DIN HEADPHONE: U1.22 (DIN), VQ1.27 (PC1)
DIN SPEAKER: U2.22 (DIN), VQ1.43 (PA7)
DIN STEREO OUT: U3.22 (DIN), VQ1.48 (PB2)
DN USB: L8.1, U24.5
DN USB 2: U22.5, VQ1.103 (PA11)
DP USB: L8.2, U24.6
DP USB 2: U22.6, VQ1.104 (PA12)
Extention: D4.1 (C), D8.1 (C), D12.1 (C), D16.1 (C), D20.1 (C), D24.1 (C), D28.1 (C), D32.1 (C), D36.1 (C), D40.1 (C), D44.1 (C), D48.1 (C), VQ1.42 (PA6)
Func Encoder A: SW59.A, VQ1.87 (PG2)
Func Encoder B: SW59.B, VQ1.82 (PD13)
Func Switch: SW59.S1, VQ1.79 (PD10)
GND: AUDIO1.4, C4.2, C5.2, C6.1, C7.1, C8.2, C9.2, C10.2, C11.1, C12.1, C13.2, C14.2, C15.2, C16.1, C17.1, C18.2, C19.2, C20.2, C21.2, C22.2, C23.2, C24.2, C25.2, C26.2, C27.2, C28.2, C29.2, C30.2, C31.2, C32.2, C33.2, C34.2, C35.2, C36.2, C37.2, C38.2, C39.2, C40.1, C41.1, C42.1, C43.1, C44.1, C45.1, C48.1, C49.1, C50.1, C51.1, C52.1, C53.1, C54.1, C55.1, C56.1, C57.1, C58.2, C59.1, C60.2, C61.2, C62.1, C63.1, C66.2, C67.2, C74.2, C75.1, C76.2, C77.2, C78.1, C79.1, C80.2, C81.2, C82.2, C83.2, C84.1, C85.1, C86.1, C87.1, C88.1, C97.1, C98.1, C99.1, C100.1, C101.2, C102.2, C103.2, C104.2, C105.1, C106.2, C107.1, C108.2, C109.1, C110.2, C111.1, C112.2, C113.1, C114.2, C115.1, C116.2, C117.1, C118.1, C119.2, C120.1, C121.2, C122.1, C123.2, C124.1, C125.2, C127.1, C128.2, C129.2, C131.2, C132.2, C133.2, C134.1, C136.2, C138.2, C140.2, C141.2, C142.2, C143.2, C144.2, C145.2, C146.2, C148.2, C149.2, C150.1, C151.2, C153.1, C154.1, C155.2, C156.2, C157.1, C159.2, C160.2, C161.2, C162.2, C164.2, C165.2, C166.2, C167.2, C168.1, C169.1, C170.1, C171.1, C172.2, C174.2, C175.2, C176.2, C177.2, C178.2, C179.2, C180.2, C181.2, C182.2, C183.2, C184.2, C185.2, C186.2, C187.2, C188.2, C189.2, C190.2, C191.1, C192.2, C193.2, C194.2, C195.2, C196.2, C197.2, C198.1, C211.2, C212.2, C213.2, C214.2, C215.2, C216.2, C217.2, C218.2, C219.2, C220.2, C221.2, C222.2, C223.2, C224.2, C225.2, C226.2, C227.2, C228.2, C229.2, C230.2, C231.2, C232.2, C233.2, C234.2, CN1.6, CN1.7, CN2.2, CN2.6, CN2.7, Card1.6 (VSS), Card1.10, Card1.11, Card1.12, Card1.13, D49.1 (K), D51.1 (K), FPC1.1, FPC1.10, FPC1.12, FPC1.13, FPC1.14, J1.2, J2.2, J5.2, J6.3, J6.4, J10.3, J10.4, J11.2, L7.2, OC1.5 (GND), R10.2, R12.1, R14.1, R20.2, R30.1, R34.1, R36.1, R37.1, R41.2, R43.2, R44.2, R49.2, R53.2, R55.2, R70.2, R76.2, R79.2, R81.2, R90.2, R91.2, R106.2, R109.1, R112.2, R122.1, R124.1, R126.1, R128.1, R130.1, R132.1, R133.1, R135.1, SW5.C, SW10.C, SW19.C, SW20.C, SW33.C, SW34.C, SW55.1, SW55.2, SW56.3, SW56.4, SW57.3, SW57.4, SW59.C, SW59.S2, U1.3 (CPGND), U1.9 (AGND), U1.16 (ADR2/GPIO2/DOUT), U1.18 (MODE2/MS), U1.24 (ADR1/MISO/FMT), U1.27 (DGND), U2.3 (CPGND), U2.9 (AGND), U2.16 (ADR2/GPIO2/DOUT), U2.18 (MODE2/MS), U2.24 (ADR1/MISO/FMT), U2.27 (DGND), U3.3 (CPGND), U3.9 (AGND), U3.16 (ADR2/GPIO2/DOUT), U3.18 (MODE2/MS), U3.24 (ADR1/MISO/FMT), U3.27 (DGND), U4.4 (IN2+), U4.6 (IN1+), U8.4 (IN2+), U8.6 (IN1+), U9.5, U10.5, U12.5, U13.1, U14.1, U15.3 (GND), U17.21 (EP), U18.1 (MODSEL), U18.9 (GND), U18.13 (AM2), U18.14 (AM1), U18.15 (AM0), U18.22 (GND), U18.25 (GND), U18.28 (GND), U18.33 (PAD), U19.1 (MODSEL), U19.9 (GND), U19.10 (LINP), U19.11 (LINN), U19.13 (AM2), U19.14 (AM1), U19.15 (AM0), U19.22 (GND), U19.25 (GND), U19.28 (GND), U19.33 (PAD), U21.8 (VSS), U21.25 (EP), U22.4, U22.7, U22.8, U23.6 (IN1+), U24.4, U24.7, U24.8, U25.17 (GND), U25.25 (GND), U27.13, U27.25, U27.36, U27.48, U28.2 (GND), U29.C2 (GND), U30.1 (S), U30.2 (S), U30.3 (S), U32.2, U32.4, U34.1 (PGND), U34.9 (EP), U35.1 (PGND), U35.9 (EP), U36.1 (PGND), U36.9 (EP), U37.1 (PGND), U37.9 (EP), U38.1 (PGND), U38.9 (EP), U39.1 (PGND), U39.9 (EP), USB1.1 (GND), USB1.12 (GND), USB1.13 (SHELL), USB1.14 (SHELL), VQ1.16 (VSS), VQ1.31 (VSSA), VQ1.38 (VSS), VQ1.51 (VSS), VQ1.61 (VSS), VQ1.83 (VSS), VQ1.94 (VSS), VQ1.107 (VSS), VQ1.120 (VSS), VQ1.130 (VSS)
GPIO3 HEADPHONE: U1.15 (GPIO3/AGNS), VQ1.49 (PF11)
GPIO3 SPEAKER: U2.15 (GPIO3/AGNS), VQ1.57 (PG1)
GPIO3 STEREO OUT: U3.15 (GPIO3/AGNS), VQ1.44 (PC4)
GPIO4 HEADPHONE: U1.14 (GPIO4/MAST), VQ1.50 (PF12)
GPIO4 SPEAKER: U2.14 (GPIO4/MAST), VQ1.64 (PE11)
GPIO4 STEREO OUT: U3.14 (GPIO4/MAST), VQ1.45 (PC5)
GPIO5 HEADPHONE: U1.13 (GPIO5/ATT0), VQ1.53 (PF13)
GPIO5 SPEAKER: U2.13 (GPIO5/ATT0), VQ1.65 (PE12)
GPIO5 STEREO OUT: U3.13 (GPIO5/ATT0), VQ1.46 (PB0)
GPIO6 HEADPHONE: U1.19 (GPIO6/FLT), VQ1.56 (PG0)
GPIO6 SPEAKER: U2.19 (GPIO6/FLT), VQ1.66 (PE13)
GPIO6 STEREO OUT: U3.19 (GPIO6/FLT), VQ1.47 (PB1)
HEADPHONE AMP L: AUDIO1.2, R117.2, U17.2 (LOUT)
HEADPHONE AMP R: AUDIO1.3, R54.1, U17.19 (ROUT)
HEADPHONE BUFF L N: R11.1, R32.2, U5.2 (OUT2)
HEADPHONE BUFF L P: R9.2, R31.1, U5.7 (IN1-), U5.8 (OUT1)
HEADPHONE BUFF R N: R24.1, R39.2, U11.2 (OUT2)
HEADPHONE BUFF R P: R19.2, R38.1, U11.7 (IN1-), U11.8 (OUT1)
HEADPHONE DAC L: C34.1, R1.2, U5.6 (IN1+)
HEADPHONE DAC R: C35.1, R2.2, U11.6 (IN1+)
HEADPHONE GPIO L: AUDIO1.6, R29.1, VQ1.67 (PE14)
HEADPHONE GPIO R: AUDIO1.7, R33.1, VQ1.68 (PE15)
INT_N USB: R85.2, U24.3, U29.B2 (INT_N)
INT_N USB 2: U22.3, VQ1.102 (PA10)
IO0: R103.2, VQ1.85 (PD14)
IO1: R102.2, VQ1.86 (PD15)
IO2: R101.2, VQ1.114 (PD0)
IO3: R100.2, VQ1.115 (PD1)
IO4: R99.2, VQ1.58 (PE7)
IO5: R98.2, VQ1.59 (PE8)
IO6: R97.2, VQ1.60 (PE9)
IO7: R96.2, VQ1.63 (PE10)
IOFF 13: J4.1, U21.11 (CS13/GPO5)
IOFF 14: J4.2, U21.10 (CS14/GPO6)
IOFF 15: J4.3, U21.9 (CS15/SH/~HI)
Keyboard Volume Encoder A: SW33.A, VQ1.129 (PG14)
Keyboard Volume Encoder B: SW33.B, VQ1.128 (PG13)
LCD CS: FPC1.2, VQ1.3 (PE4)
LCD RESET: FPC1.6, VQ1.2 (PE3)
LCD RS: FPC1.3, VQ1.4 (PE5)
LCD SCL: FPC1.4, VQ1.1 (PE2)
LCD SDA: FPC1.5, VQ1.5 (PE6)
LRCK HEADPHONE: U1.23 (LRCK), VQ1.73 (PB12)
LRCK SPEAKER: U2.23 (LRCK), VQ1.110 (PA15)
LRCK STEREO OUT: U3.23 (LRCK), VQ1.40 (PA4)
MONO BUFF: R116.1, U8.8 (OUT1), U15.9 (NC1)
MUTE SUB: R49.1, U19.12 (MUTE), VQ1.140 (PB9)
MUTE TWEET/WOOF: R44.1, U18.12 (MUTE), VQ1.142 (PE1)
Main On/Off Switch: U9.6, VQ1.105 (PA13)
Main Volume Encoder A: SW5.A, VQ1.139 (PB8)
Main Volume Encoder B: SW5.B, VQ1.132 (PG15)
Mayor: D1.1 (C), D5.1 (C), D9.1 (C), D13.1 (C), D17.1 (C), D21.1 (C), D25.1 (C), D29.1 (C), D33.1 (C), D37.1 (C), D41.1 (C), D45.1 (C), VQ1.29 (PC3_C)
Metronome On/Off Switch: U14.2, VQ1.100 (PA8)
Minor: D2.1 (C), D6.1 (C), D10.1 (C), D14.1 (C), D18.1 (C), D22.1 (C), D26.1 (C), D30.1 (C), D34.1 (C), D38.1 (C), D42.1 (C), D46.1 (C), VQ1.36 (PA2)
unnamed: C46.2, C47.1, R12.2
unnamed: C56.2, R21.1, R25.2
unnamed: C64.1, C65.2, R34.2
unnamed: C78.2, R50.1
unnamed: C118.2, R64.2
unnamed: C119.1, R65.1
unnamed: C120.2, R66.2
unnamed: C121.1, R67.1
unnamed: C122.2, R68.2
unnamed: C123.1, R69.1
unnamed: C125.1, R73.1
unnamed: C188.1, C196.1, VQ1.71 (VCAP), VQ1.106 (VCAP)
unnamed: CN1.4, R27.2
unnamed: CN1.5, D50.2 (A), OC1.2
unnamed: CN2.4, R26.2
unnamed: CN2.5, R28.2
unnamed: D1.2 (A), SW1.1, SW1.2
unnamed: D2.2 (A), SW2.1, SW2.2
unnamed: D3.2 (A), SW3.1, SW3.2
unnamed: D4.2 (A), SW4.1, SW4.2
unnamed: D5.2 (A), SW6.1, SW6.2
unnamed: D6.2 (A), SW7.1, SW7.2
unnamed: D7.2 (A), SW8.1, SW8.2
unnamed: D8.2 (A), SW9.1, SW9.2
unnamed: D9.2 (A), SW11.1, SW11.2
unnamed: D10.2 (A), SW12.1, SW12.2
unnamed: D11.2 (A), SW13.1, SW13.2
unnamed: D12.2 (A), SW14.1, SW14.2
unnamed: D13.2 (A), SW15.1, SW15.2
unnamed: D14.2 (A), SW16.1, SW16.2
unnamed: D15.2 (A), SW17.1, SW17.2
unnamed: D16.2 (A), SW18.1, SW18.2
unnamed: D17.2 (A), SW21.1, SW21.2
unnamed: D18.2 (A), SW22.1, SW22.2
unnamed: D19.2 (A), SW23.1, SW23.2
unnamed: D20.2 (A), SW24.1, SW24.2
unnamed: D21.2 (A), SW25.1, SW25.2
unnamed: D22.2 (A), SW26.1, SW26.2
unnamed: D23.2 (A), SW27.1, SW27.2
unnamed: D24.2 (A), SW28.1, SW28.2
unnamed: D25.2 (A), SW29.1, SW29.2
unnamed: D26.2 (A), SW30.1, SW30.2
unnamed: D27.2 (A), SW31.1, SW31.2
unnamed: D28.2 (A), SW32.1, SW32.2
unnamed: D29.2 (A), SW35.1, SW35.2
unnamed: D30.2 (A), SW36.1, SW36.2
unnamed: D31.2 (A), SW37.1, SW37.2
unnamed: D32.2 (A), SW38.1, SW38.2
unnamed: D33.2 (A), SW39.1, SW39.2
unnamed: D34.2 (A), SW40.1, SW40.2
unnamed: D35.2 (A), SW41.1, SW41.2
unnamed: D36.2 (A), SW42.1, SW42.2
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

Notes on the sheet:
Main Knobs
Pedal
Audio Out
Next Chord
Octave Down
Function Knob
Sonic Strings
Advanced Functionalities
Sustain Chord
On/Off
Rythm Volume
I/O
Main Volume
Headphones Out
Metronome
Main
Octave Up
Keyboard Volume
Recording Mode
Main Buttons
Volume
Connect int a gpio exti
Chords Volume
Vibrato Knob
Chord Matrix
Touch Pad Volume
Rythm
Instant Off
Power Managment
Stereo Out
Recording

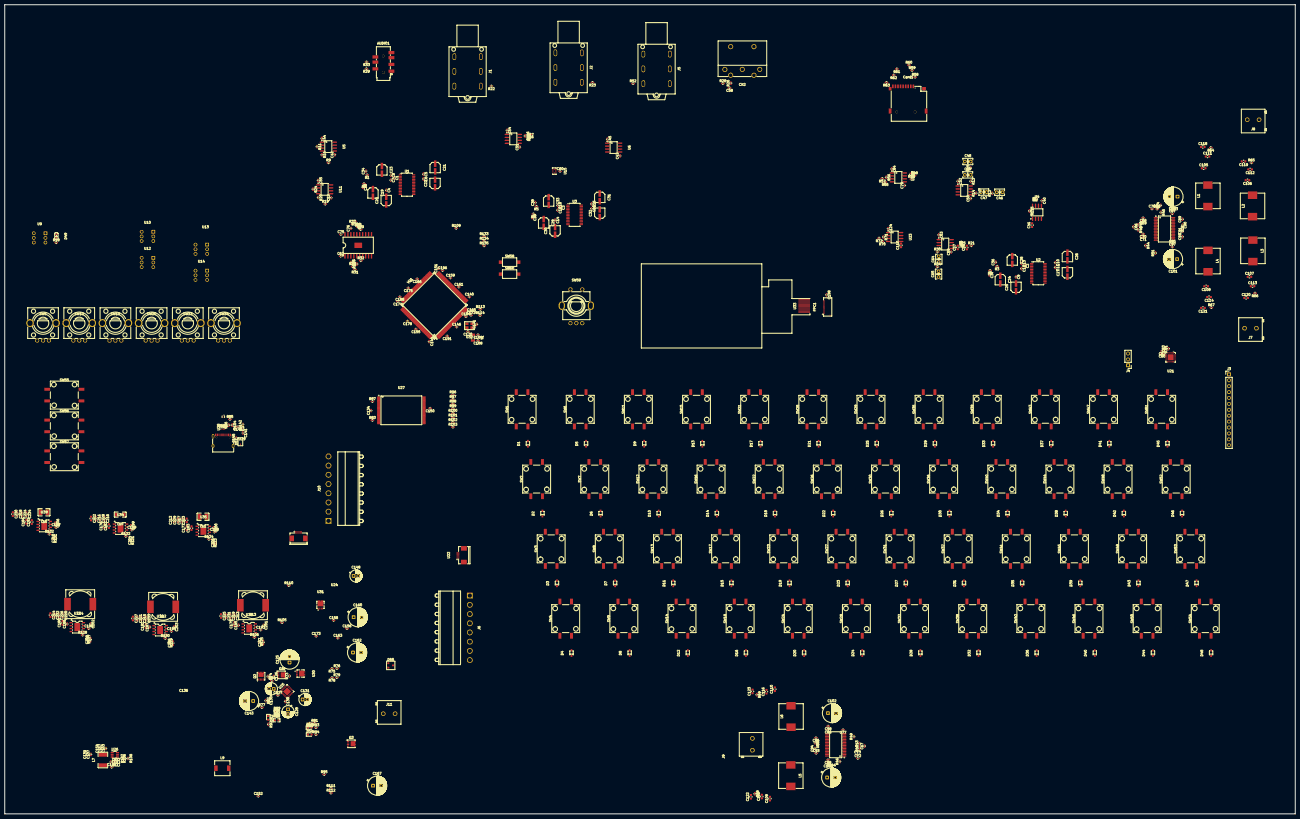
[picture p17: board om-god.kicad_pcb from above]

Board: 4 copper layers, 554.9 x 347.9 mm, 552 parts (0 on the bottom side), 380 nets, no tracks yet.

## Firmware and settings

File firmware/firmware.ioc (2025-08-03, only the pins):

Mcu.UserName=STM32H723ZGTx
PA0.Signal=UART4_TX
PA1.Signal=UART4_RX
PA10.Signal=GPXTI10
PA11.Signal=USB_OTG_HS_DM
PA12.Signal=USB_OTG_HS_DP
PA15(JTDI).Signal=I2S1_WS
PA4.Signal=I2S3_WS
PA5.Signal=I2S1_CK
PA7.Signal=I2S1_SDO
PA9.Signal=USB_OTG_HS_VBUS
PB10.Signal=I2S2_CK
PB12.Signal=I2S2_WS
PB13.Signal=SDMMC1_D0
PB2.Signal=I2S3_SDO
PB3(JTDO/TRACESWO).Signal=I2S3_CK
PB6.Signal=I2C1_SCL
PB7.Signal=I2C1_SDA
PC1.Signal=I2S2_SDO
PC10.Signal=SDMMC1_D2
PC11.Signal=SDMMC1_D3
PC12.Signal=SDMMC1_CK
PC14-OSC32_IN.Signal=RCC_OSC32_IN
PC15-OSC32_OUT.Signal=RCC_OSC32_OUT
PC6.Signal=FMC_NWAIT
PC8.Signal=FMC_NCE
PC9.Signal=SDMMC1_D1
PD0.Signal=FMC_D2_DA2
PD1.Signal=FMC_D3_DA3
PD11.Signal=FMC_A16_CLE
PD12.Signal=FMC_A17_ALE
PD14.Signal=FMC_D0_DA0
PD15.Signal=FMC_D1_DA1
PD2.Signal=SDMMC1_CMD
PD4.Signal=FMC_NOE
PD5.Signal=FMC_NWE
PE10.Signal=FMC_D7_DA7
PE2.Signal=SPI4_SCK
PE4.Signal=SPI4_NSS
PE6.Signal=SPI4_MOSI
PE7.Signal=FMC_D4_DA4
PE8.Signal=FMC_D5_DA5
PE9.Signal=FMC_D6_DA6
PF0.Signal=I2C2_SDA
PF1.Signal=I2C2_SCL
PF14.Signal=I2C4_SCL
PF15.Signal=I2C4_SDA
PH0-OSC_IN.Signal=RCC_OSC_IN
PH1-OSC_OUT.Signal=RCC_OSC_OUT

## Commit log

2025-08-01 ñushsh
    [bom.csv, designators.csv, om-god.kicad_pcb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]
2025-08-16 added stuff
    [om-god.kicad_sch]
